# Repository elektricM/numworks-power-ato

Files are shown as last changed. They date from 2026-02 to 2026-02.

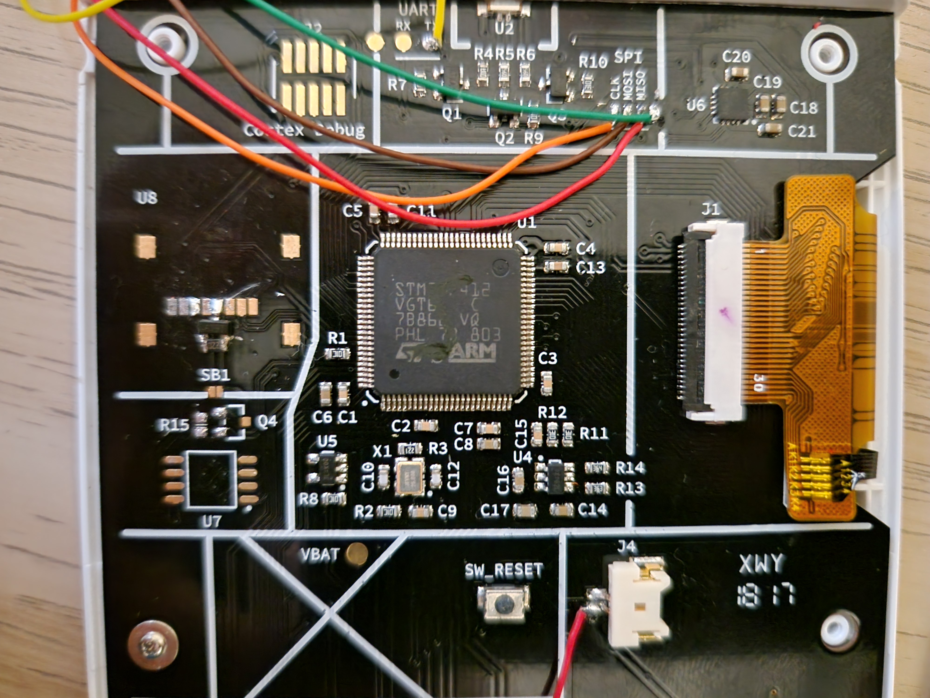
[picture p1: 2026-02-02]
docs/photos/n0100-pcb-closeup.jpg

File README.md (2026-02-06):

# NumWorks N0100 Power Module



[]()

Custom power management board for running a Raspberry Pi Zero 2W inside a NumWorks N0100 calculator.

Schematic

## Why This Exists

The [numworks-rpi](https://github.com/elektricM/numworks-rpi) project replaces the internals of a NumWorks calculator with a Raspberry Pi Zero 2W running Linux. This requires a custom power solution that can:
- ✅ Charge the Li-Ion battery (replacing the failed RT9526A charger)
- ✅ Protect the battery (overcurrent, overvoltage, undervoltage)
- ✅ Provide stable 5V power for the Raspberry Pi from a 3.7V battery
- ✅ Fit within the calculator's tight space constraints (38x24mm max)

This board does all of that in a single custom PCB.

## What It Does

**Three integrated circuits on one compact board:**

### 1. TP4056 Li-Ion Charger
Replaces the dead RT9526A charger on the original calculator. Standard 1A charge current with automatic termination.

### 2. DW01A + FS8205A Battery Protection
Complete protection circuitry:
- Overcurrent protection (discharge > 3A, charge > 1.5A)
- Overvoltage protection (> 4.25V)
- Undervoltage protection (< 2.4V)
- Auto-recovery when fault conditions clear

### 3. TPS63020 Buck-Boost Converter
Maintains stable 5V output for the Raspberry Pi across the full battery voltage range (3.0V - 4.2V):
- 95% efficiency typical
- Up to 2A output current
- Seamless transition between buck and boost modes

## Why atopile?

This board is designed with [atopile](https://atopile.io), a modern code-first PCB design tool, instead of traditional KiCad or Altium.

**Benefits:**
- 📝 **Version control friendly** — Circuit described in plain text, easy to diff and review
- 🔍 **Automatic part sourcing** — Searches JLCPCB/LCSC inventory for available parts
- 🔄 **Parametric components** — Easy to swap parts while maintaining electrical compatibility
- 🧪 **Design validation** — Catch errors before layout with built-in checking

All components are sourced from JLCPCB/LCSC for straightforward assembly and low-cost manufacturing.

## Component Selection

| Component | Part Number | Why This One |
|---|---|---|
| Charger IC | TP4056 | Ubiquitous, cheap (~$0.10), proven reliability, 1A charge current matches original |
| Protection IC | DW01A | Industry standard battery protection IC, tiny SOT-23-6 package |
| Protection MOSFETs | FS8205A | Dual N-channel MOSFETs in SOT-23-6, perfectly matched for DW01A |
| Buck-Boost | TPS63020 | Can operate in buck OR boost mode, 95% efficiency, up to 2A output, small footprint |

Full design rationale and power budget analysis available in [docs/design-spec.md](docs/design-spec.md).

## Board Specifications

- **Dimensions:** 38mm × 24mm (fits NumWorks internal space)
- **Input voltage:** USB 5V (charging) or battery 3.0V-4.2V (operation)
- **Output voltage:** 5.0V ± 2% (for Raspberry Pi)
- **Maximum output current:** 2A continuous (sufficient for RPi Zero 2W)
- **Charge current:** 1A (programmable via resistor)
- **Layers:** 2-layer PCB
- **Manufacturing:** Designed for JLCPCB assembly

## Status

✅ **Tested and working** — Successfully integrated into the numworks-rpi project. Powers the Raspberry Pi Zero 2W reliably with good battery life.

## Building

Requires [atopile](https://atopile.io) v0.14.0 or newer.

```bash
# Install atopile
pip install atopile

# Build the design
ato build

# Output files will be in build/
```

The build generates:
- Netlist (JSON)
- Schematic (SVG)
- Layout files for manufacturing

## Related Projects

- **[numworks-rpi](https://github.com/elektricM/numworks-rpi)** — Main project: Raspberry Pi Zero 2W running Linux inside a NumWorks calculator
- **[numworks-power-pcb](https://github.com/elektricM/numworks-power-pcb)** — Earlier KiCad-based version of this board (deprecated)

## Documentation

- **[Design Spec](docs/design-spec.md)** — Complete circuit design, pin mappings, component selection rationale, and power budget calculations
- **[Tool Learnings](docs/tool-learnings.md)** — Comparison of PCB design tools: atopile vs traditional EDA

## Project Structure

```
numworks-power-ato/
├── ato.yaml              # atopile project configuration
├── main.ato              # Top-level circuit definition
├── parts/                # Component library (charger, protection, buck-boost)
├── layouts/              # PCB layout definitions
├── docs/                 # Design documentation
│   ├── design-spec.md    # Circuit design and analysis
│   └── tool-learnings.md # PCB tool comparison
├── schematic.svg         # Generated schematic image
└── *.py                  # Build and layout automation scripts
```

## Manufacturing

This board is designed for JLCPCB's PCB assembly service:
1. Export Gerber files from atopile build output
2. Upload to JLCPCB
3. All components are in JLCPCB's parts library
4. SMT assembly is straightforward with BOM and pick-place files

## License

MIT License — see [LICENSE.txt](LICENSE.txt) for details.

---

**Part of the [numworks-rpi](https://github.com/elektricM/numworks-rpi) project**

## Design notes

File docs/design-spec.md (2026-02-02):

# NumWorks N0100 Power Module — Design Spec

## Purpose
Internal daughter board replacing the broken RT9526A charger on a NumWorks N0100 calculator.
Also adds 5V regulated output for a Raspberry Pi Zero 2W mounted inside the calculator.

## Target Hardware
- **Calculator:** NumWorks N0100 (STM32F412, micro-USB, 1820mAh Li-Ion battery, 2.8V logic rail)
- **Schematics:** https://tiplanet.org/forum/archives_voir.php?id=2637409

## What This Board Does
1. **Li-Ion charging** — TP4056 linear charger, 500mA from USB
2. **Battery protection** — DW01A + FS8205A (over-charge, over-discharge, over-current, short-circuit)
3. **5V buck-boost** — TPS63020, 3.0–4.2V → 5.0V for Pi Zero 2W (up to 2A transient)
4. **Battery monitoring** — 1:1 voltage divider for STM32 ADC

## What This Board Does NOT Include
- ❌ USB connector (on mainboard)
- ❌ JST battery connector (wires/solder pads)
- ❌ ESD protection (USBLC6-2SC6 already on mainboard)
- ❌ 2.8V LDO (RT9078 stays on mainboard)
- ❌ Backlight driver (RT9365 stays on mainboard)

## Physical Constraints
- Board sits inside the calculator — must be small and flat
- No tall components, no through-hole connectors
- All connections via solder pads + wires to mainboard
- Passives: 0402/0603 preferred

## Wire Signals to Mainboard
| Signal | Direction | Connects To | Notes |
|---|---|---|---|
| VUSB | In from MB | Mainboard USB 5V | Power source for charger |
| GND | Common | System ground | |
| VBAT_RAW  | Bidirectional | Battery + | Charger output / battery input |
| BAT_NEG | To battery | Battery − | Through protection MOSFETs |
| V5_PI | Out to Pi | Pi Zero 5V rail | TPS63020 output |
| PI_EN | In from STM32 | STM32 PB9 | High = enable Pi power |
| CHG_STAT  | Out to STM32  | STM32 PA0 | Active-low charging indicator |
| VBAT_SNS  | Out to STM32  | STM32 PA1 | Battery voltage / 2 (ADC input) |

## ICs
| IC | Function | Package | LCSC |
|---|---|---|---|
| TP4056 | Li-Ion charger | ESOP-8 | C16581 |
| DW01A | Battery protection | SOT-23-6  | C351410  |
| FS8205A | Dual N-MOSFET | SOT-23-6  | C32254 |
| TPS63020 | Buck-boost converter | VSON-14 | C15483 |

## Key Design Values
- **Charge current:** 500mA (R_PROG = 2kΩ)
- **Buck-boost output:** 5.045V (R_top = 1MΩ, R_bot = 110kΩ)
- **PI_EN default:** OFF (100kΩ pull-down, STM32 drives high)
- **PS/SYNC:** Forced PWM mode (100kΩ pull-down)
- **Battery monitor:** 1:1 divider (2× 1MΩ) + 100nF filter → VBAT/2 at ADC
- **Inductor:** 2.2µH, 3A rated
- **Current sense:** 100Ω between battery − and DW01A VM pin

## Power Budget (1820mAh battery)
- Calculator only: ~90mA → ~20h runtime
- Pi idle: ~250mA → ~5h runtime (from ~1450mAh usable)
- Pi + calc active: ~350mA → ~4h runtime

## Existing Mainboard Components (kept)
- **RT9078:** 2.8V LDO for STM32 logic
- **RT9365:** Backlight LED driver
- **USBLC6-2SC6:** USB ESD protection

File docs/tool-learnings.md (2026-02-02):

# PCB Design Tools — Learnings & Comparison

## Project Context
- **Goal:** Internal daughter board for NumWorks N0100 calculator
- **Function:** TP4056 charger + DW01A/FS8205A protection + TPS63020 5V boost for Raspberry Pi Zero 2W
- **Key constraint:** This is an INTERNAL board — no USB connector, no battery connector (JST), no ESD. VUSB comes via wire from mainboard. Battery connects directly via solder pads/wires. Minimal connectors.
- **Board sits inside the calculator** — space is extremely limited

## What NOT to Include
- ❌ USB connector (already on mainboard)
- ❌ JST battery connector (battery soldered/wired directly)
- ❌ ESD protection (already on mainboard)
- ❌ Excessive through-hole pin headers — use solder pads or minimal flat connectors
- The board should be as small and flat as possible

## Tool 1: Zener (Diode `pcb` CLI)

### What It Is
- Rust CLI tool from [Diode Inc](https://github.com/diodeinc/pcb)
- HDL language (`.zen` files) based on Starlark (Python-like)
- Version: 0.3.31
- ~Newer, smaller community

### What Works
- `pcb build` — compiles .zen to netlist, validates, generates BOM
- `pcb layout` — places all footprints with net assignments into a `.kicad_pcb`
- `pcb bom` — auto-matches generic passives to real MPNs (Murata caps, Panasonic resistors)
- `pcb search` — component search
- References KiCad symbol/footprint libraries directly (`@kicad-symbols/`, `@kicad-footprints/`)
- **VSCode extension** (`diode-inc.zener`) renders .zen as interactive schematics — **this is the visualization solution**

### What Doesn't Work Well
- Layout is grid-placed only (no intelligent grouping or autorouting)
- No CLI schematic export (must use VSCode extension for visual schematics)
- Custom components with `Symbol(definition=...)` work for build but don't get real KiCad symbols in schematic view
- Auth required for some features — login via `pcb auth login` (browser OAuth flow)

### Auth Status
- Martin has an account on the Mac (email: dolezelektricm@gmail.com)
- Token refreshes with `pcb auth refresh`
- **Server needs its own login** — can be done via browser, needs email OTP

### Key Syntax
```python
# Generics (auto-matched to real parts)
Resistor = Module("@stdlib/generics/Resistor.zen")
Capacitor = Module("@stdlib/generics/Capacitor.zen")

# KiCad library components
Component(
    name = "U1",
    symbol = Symbol(library = "@kicad-symbols/Battery_Management.kicad_sym", name = "DW01A"),
    footprint = File("@kicad-footprints/Package_TO_SOT_SMD.pretty/SOT-23-6.kicad_mod"),
    mpn = "DW01A",
    pins = { "VCC": vcc_net, "GND": gnd_net, ... },
)

# Nets
gnd = Ground("GND")
vcc = Power("VCC", voltage = VoltageRange("3.0V to 4.2V"))
my_net = Net("MY_NET")
```

### Project Location
- Workspace: `~/clawd/numworks-power-pcb/`
- GitHub: `elektricM/numworks-power-pcb`
- Entry: `boards/PowerModule/PowerModule.zen`

---

## Tool 2: atopile

### What It Is
- Python-based PCB design language (`.ato` files)
- From [atopile](https://github.com/atopile/atopile) — ~3k GitHub stars
- Version: 0.12.5 (latest: 0.14.0)
- More active community, Discord, package registry

### What Works
- `ato create part` — fetches component from JLCPCB/LCSC by part number, auto-generates footprint + symbol + 3D model
- `ato build` — compiles, picks passive components automatically from JLCPCB library
- `ato view` — schematic/block diagram visualization
- **VSCode/Cursor extension** available
- Package registry at packages.atopile.io
- Has MCP server for AI coding assistance

### What Doesn't Work Well (v0.12.5)
- `Resistor`, `Capacitor`, `Inductor` are NOT importable from `"generics/*.ato"` — the import path is wrong or they're Python-native classes in faebryk
- The `#pragma experiment("TRAITS")` flag is needed for component traits
- Interactive CLI (`ato create part`) doesn't work well in non-interactive/piped mode
- KiCad plugin installation fails on headless server (needs KiCad config path)

### Auth
- No auth needed for basic usage
- JLCPCB component fetch works without login

### Key Syntax
```
#pragma experiment("TRAITS")

module MyCircuit:
    signal vcc
    signal gnd

    r1 = new Resistor
    r1.resistance = 10kohm +/- 5%
    r1.package = "0603"
    r1.p1 ~ vcc
    r1.p2 ~ gnd

    ic = new MyCustomComponent
    ic.VIN ~ vcc
    ic.GND ~ gnd
```

### Component Creation
```bash
# Search by LCSC part number
ato create part  # then enter C16581 for TP4056

# Successfully fetched:
# - C16581 → TP4056 (TOPPOWER)
# - C351410 → DW01A (PUOLOP)
# - C32254 → FS8205A (Fortune Semicon)
# - C15483 → TPS63020DSJR (Texas Instruments)
```

### Project Location
- Workspace: `~/clawd/numworks-power-ato/`
- Not yet on GitHub

---

## Comparison

| Feature | Zener | atopile |
|---|---|---|
| Language | Starlark (.zen) | Custom (.ato) |
| Community | Smaller | ~3k stars, active |
| Passive auto-pick | ✅ Via stdlib generics | ✅ Via JLCPCB database |
| Component fetch | Manual symbol/footprint | `ato create part` (auto) |
| Schematic view | VSCode extension | `ato view` + VSCode |
| KiCad output | ✅ .kicad_pcb | ✅ .kicad_pcb |
| BOM | ✅ Great | ✅ Auto from JLCPCB |
| Layout | Grid placement | Grid placement |
| Maturity | Newer | More mature |
| Docs | Embedded (`pcb doc`) | docs.atopile.io |

## Recommendation
Both tools produce KiCad PCB output with grid-placed footprints. Manual routing in KiCad is needed either way.

**atopile** has the edge for:
- Larger community, more examples
- Better component fetching (LCSC/JLCPCB integrated)
- `ato view` for visualization without needing VSCode
- Auto parametric picking of discretes

**Zener** has the edge for:
- Direct KiCad library integration
- BOM with real MPN matching
- Slightly cleaner syntax
- Built-in simulation (`pcb sim`)

## Next Steps
1. Pick one tool (recommend trying atopile v0.14.0 for better stability)
2. Design the circuit with MINIMAL connectors — just solder pads for wires
3. Get schematic visualization working first
4. Then proceed to layout

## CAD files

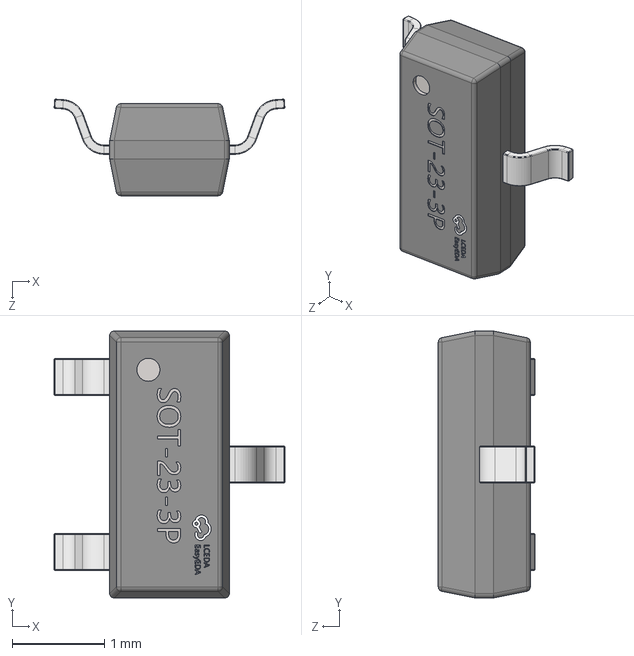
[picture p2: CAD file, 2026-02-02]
parts/Alpha___Omega_Semicon_AO3401A/SOT-23-3P_L2.9-W1.3-H1.0-LS2.4-P0.95.step
2.51 x 2.90 x 1.05 mm

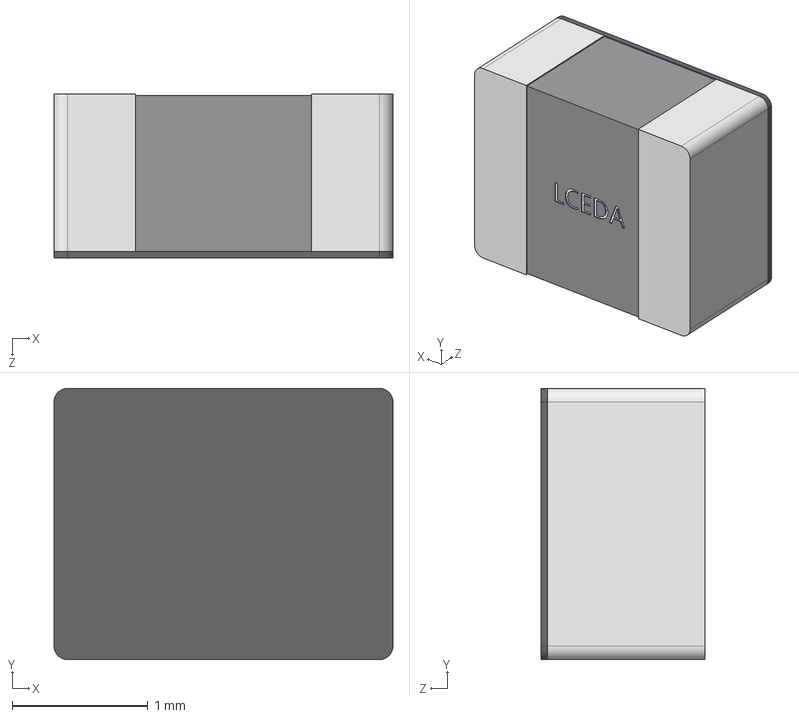
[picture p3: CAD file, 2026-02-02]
parts/cjiang_FTC252012S2R2MBCA/IND-SMD_L2.5-W2.0_MHCHL2520.STEP
2.50 x 2.00 x 1.21 mm

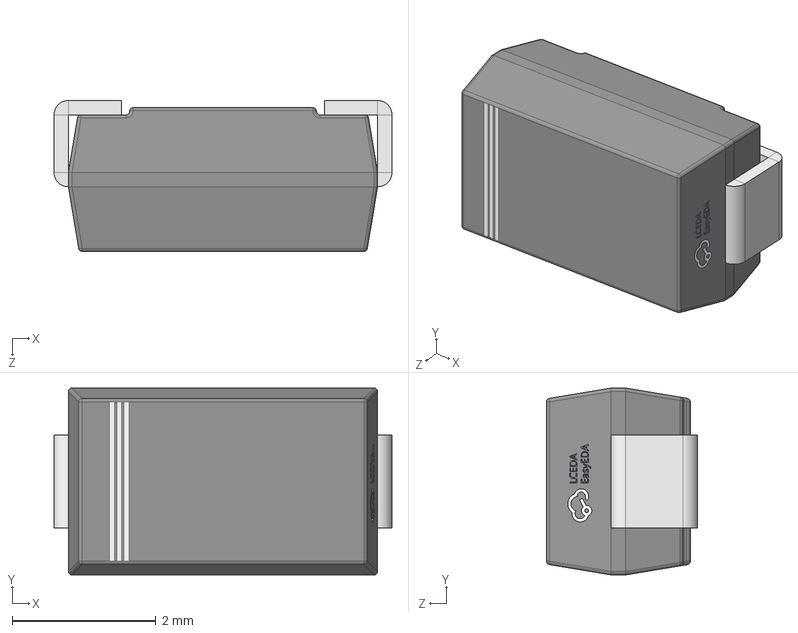
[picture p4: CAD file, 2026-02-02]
parts/MDD_Microdiode_Electronics_SS34/SMA_L4.3-W2.6-LS5.2-RD.step
4.70 x 2.60 x 2.10 mm

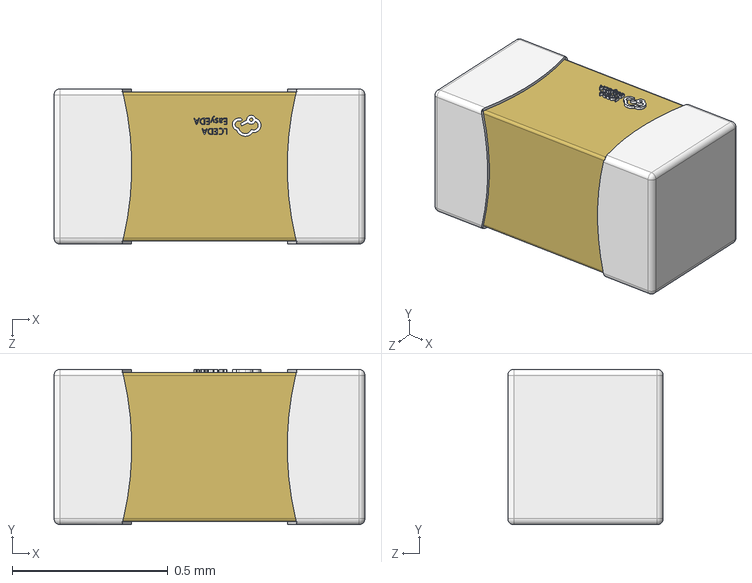
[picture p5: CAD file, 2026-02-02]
parts/Samsung_Electro_Mechanics_CL05B104KO5NNNC/C0402_L1.0-W0.5-H0.5.step
1.00 x 0.5 x 0.5 mm

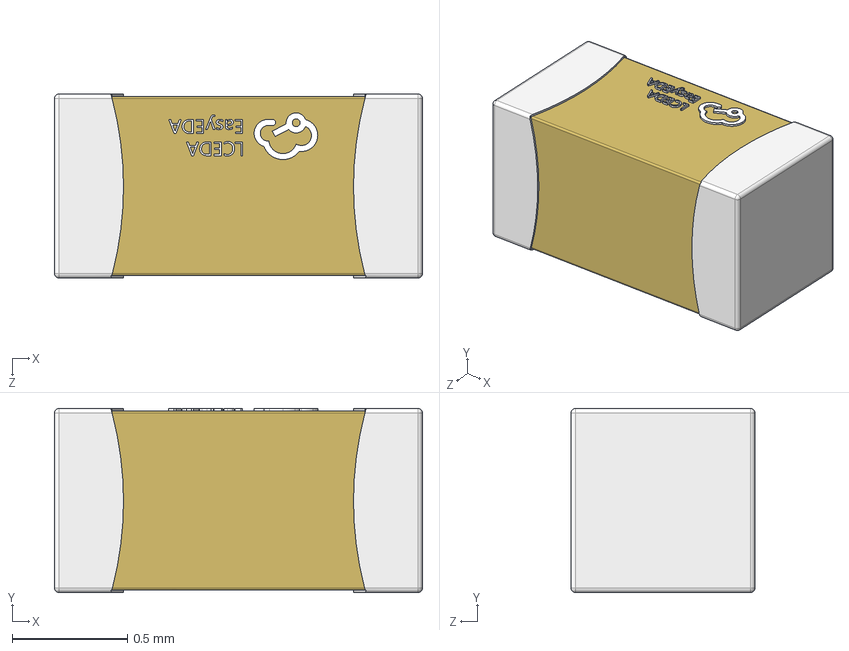
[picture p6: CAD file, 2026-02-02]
parts/Samsung_Electro_Mechanics_CL10A106KP8NNNC/C0603_L1.6-W0.8-H0.8.step
1.60 x 0.8 x 0.8 mm

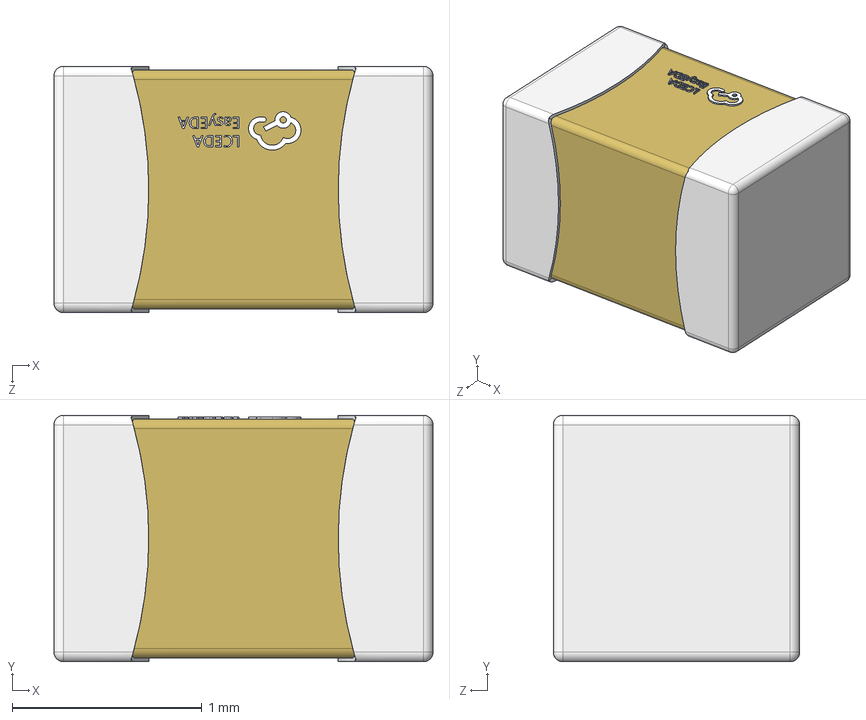
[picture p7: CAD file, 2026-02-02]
parts/Samsung_Electro_Mechanics_CL21A226MAQNNNE/C0805_L2.0-W1.3-H1.3.step
2.00 x 1.30 x 1.30 mm

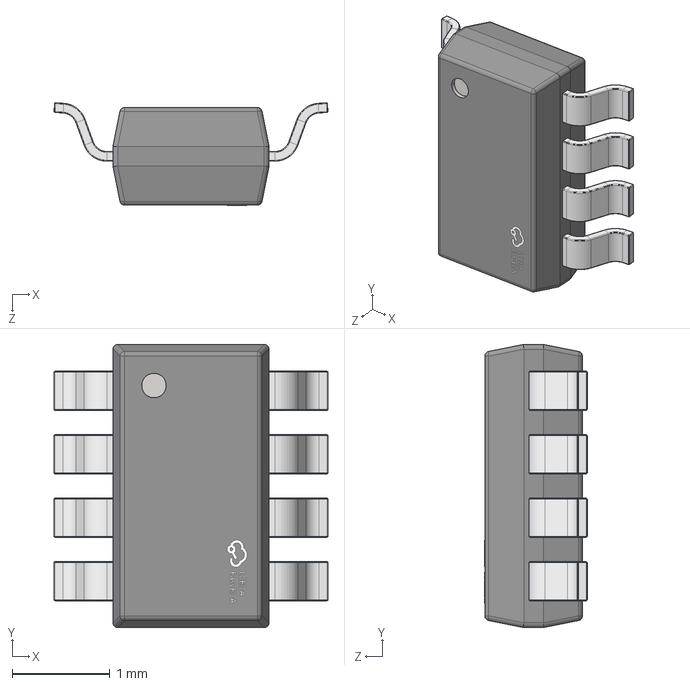
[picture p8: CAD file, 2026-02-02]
parts/Silergy_Corp_SY8303AIC/TSOT-23-8_L2.9-W1.6-H1.1-LS2.8-P0.65.step
2.81 x 2.90 x 1.05 mm

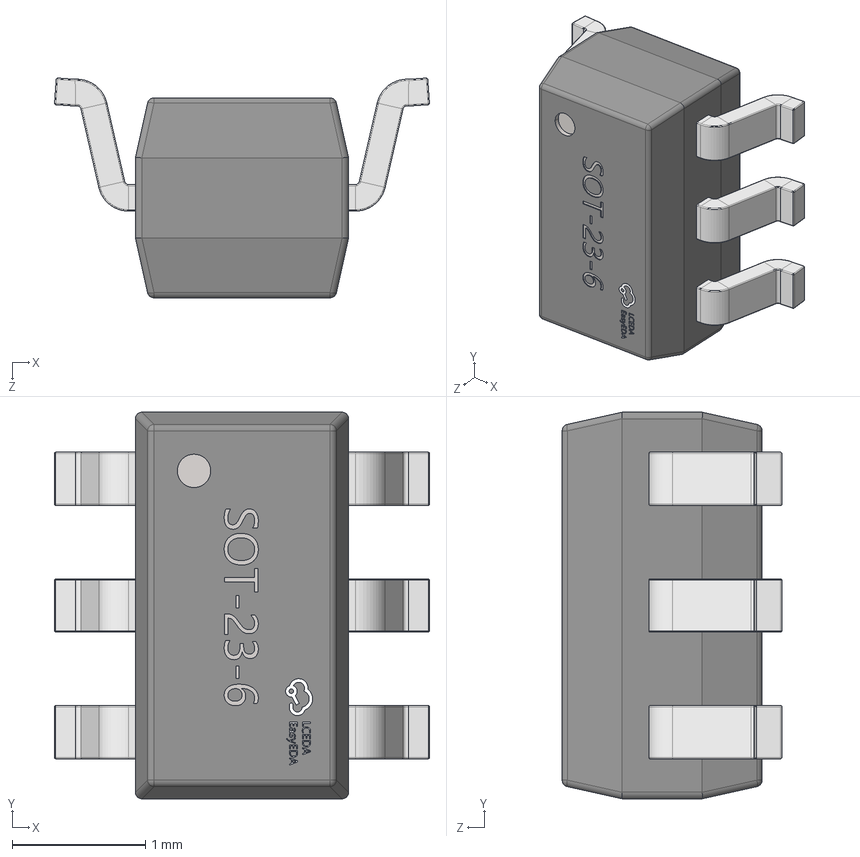
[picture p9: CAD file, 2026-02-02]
parts/SX_SX1308/SOT-23-6_L2.9-W1.6-H1.5-LS2.8-P0.95.step
2.81 x 2.90 x 1.65 mm

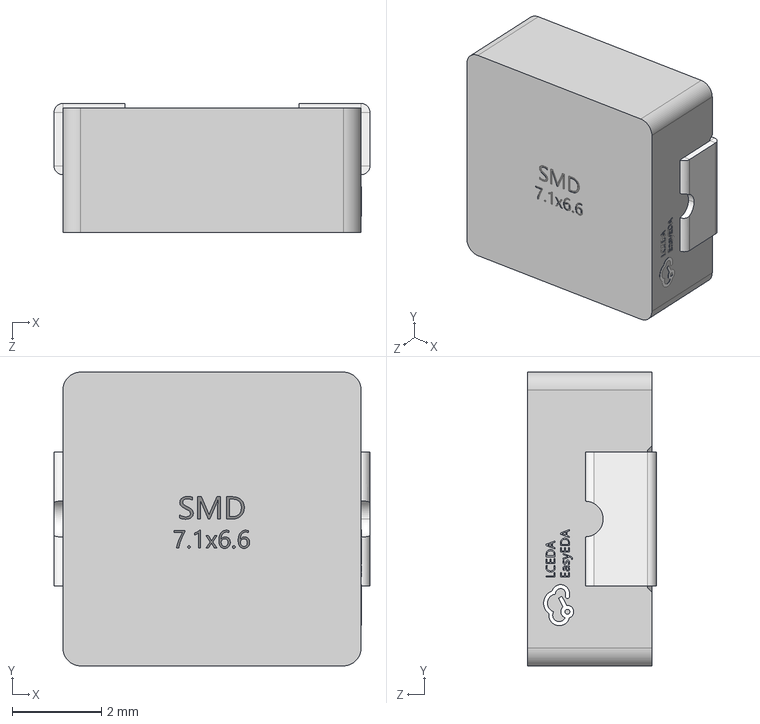
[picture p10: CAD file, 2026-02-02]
parts/SXN_SMMS0630_220M/IND-SMD_L7.1-W6.6-H2.8.step
7.10 x 6.60 x 2.90 mm

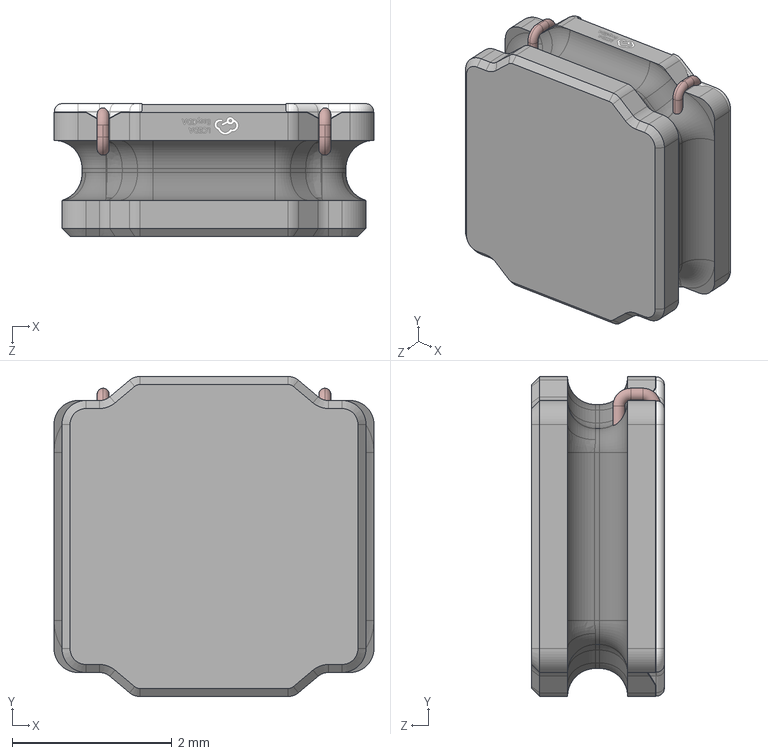
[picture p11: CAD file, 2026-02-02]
parts/SXN_SMNR4020_22UH/IND-SMD_L4.0-W4.0-H1.65.STEP
4.00 x 4.00 x 1.66 mm

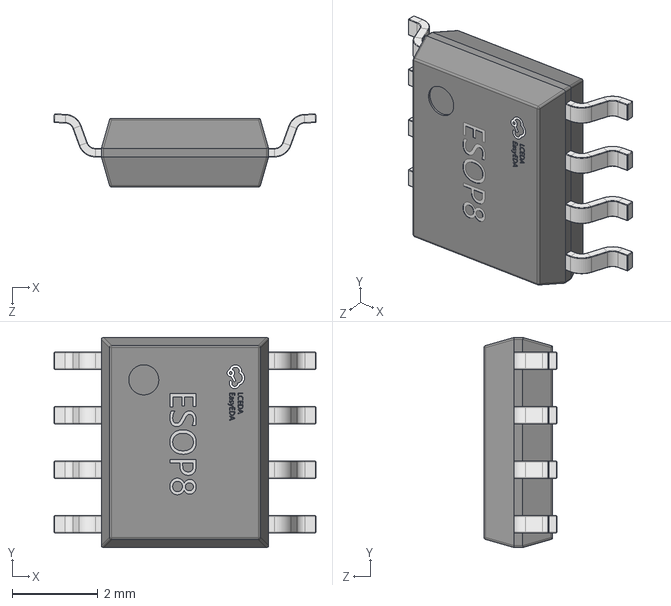
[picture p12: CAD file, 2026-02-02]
parts/TOPPOWER_TP4056_42_ESOP8/ESOP-8_L4.9-W3.9-H1.6-LS6.0-P1.27.step
6.11 x 4.90 x 1.70 mm

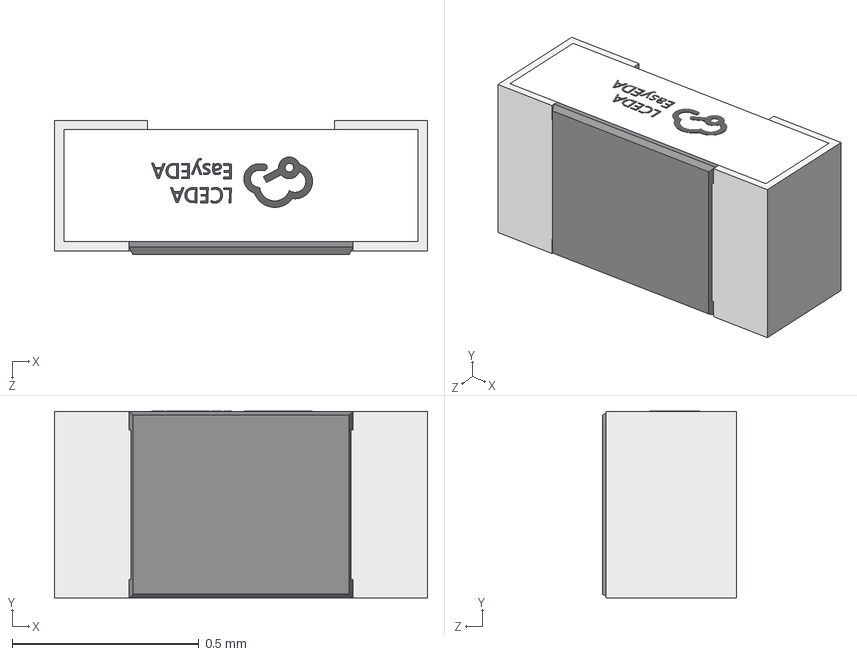
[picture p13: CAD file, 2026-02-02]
parts/UNI_ROYAL_0402WGF2203TCE/R0402_L1.0-W0.5-H0.4.step
1.00 x 0.501 x 0.36 mm

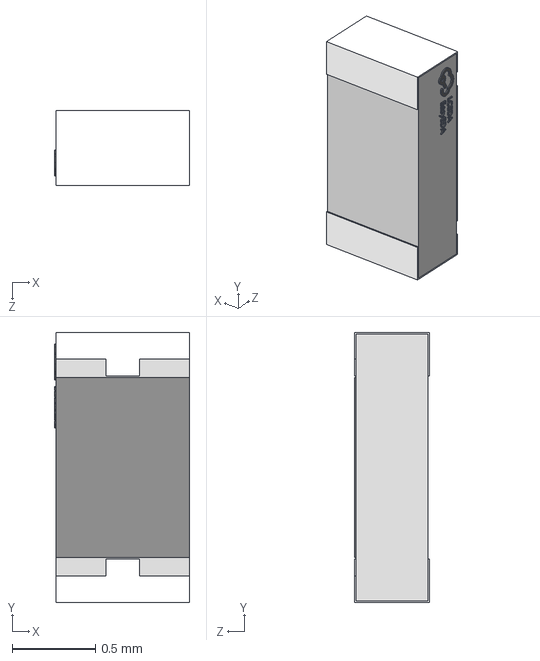
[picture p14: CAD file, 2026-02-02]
parts/UNI_ROYAL_0603WAF2203T5E/R0603.STEP
0.81 x 1.62 x 0.45 mm

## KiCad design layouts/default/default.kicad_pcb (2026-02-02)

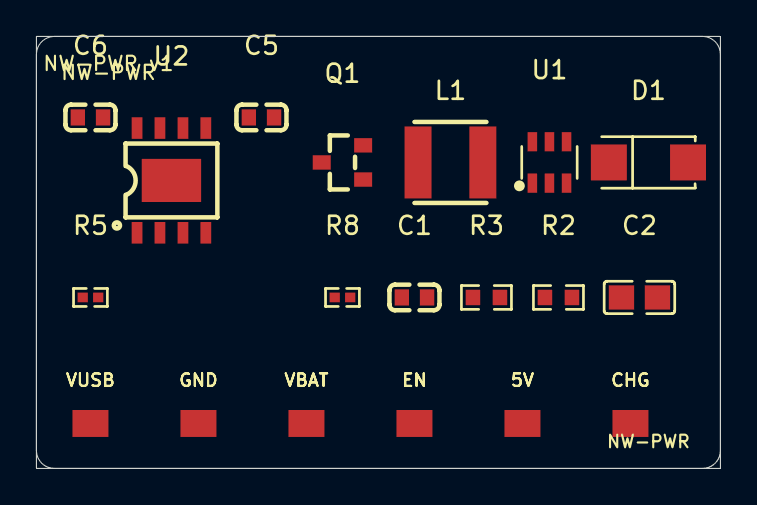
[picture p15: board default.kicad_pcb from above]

Board: 2 copper layers, 38.0 x 24.0 mm, 19 parts (0 on the bottom side), 10 nets, no tracks yet.

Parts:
C1, C5, C6: 0F; C0603
C2: 0F; C0805
D1: SMA_L4.3-W2.6-LS5.2-RD
J1, J2, J3, J4, J5, J6: SolderPad
L1: IND-SMD_L4.0-W4.0_LQH44PN2R2MP0L
Q1: SOT-23_L2.9-W1.3-P1.90-LS2.4-BR
R2: 30000Ω; R0603
R3: 220000Ω; R0603
R5: 2000Ω; R0402
R8: 100000Ω; R0402
U1: SOT-23-6_L2.9-W1.6-P0.95-LS2.8-BL
U2: ESOP-8_L4.9-W3.9-P1.27-LS6.0-BL-EP

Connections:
2: D1.2, L1.2, U1.1
FB: R2.1, R3.2, U1.3
PROG: R5.1, U2.2
c_bat-power-hv: C5.1, J5.1, Q1.2, R8.1, U2.5
c_in-power-hv: C6.1, J6.1, U2.4, U2.8
c_out-power-hv: C2.1, D1.1, J4.1, R3.1
chg_stat: J1.1, U2.7
hv: C1.1, L1.1, Q1.3, U1.4, U1.5
lv: C1.2, C2.2, C5.2, C6.2, J2.1, R2.2, R5.2, U1.2, U2.1, U2.3, U2.9
pi_en: J3.1, Q1.1, R8.2

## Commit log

2026-02-02 NumWorks N0100 power module - atopile build (TP4056 + DW01A + TPS63020)
    [C0402_L1.0-W0.5-H0.5.step, C0603_L1.6-W0.8-H0.8.step, C0805_L2.0-W1.3-H1.3.step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]
2026-02-02 Upgrade to atopile v0.14.0 (Python 3.14), fix pin names
    [default.kicad_pcb]
2026-02-02 Rearrange PCB layout: group by functional block (buck-boost/charger/protection/monitor), add 39.5x16.5mm board outline
    [default.kicad_pcb]
2026-02-02 Clean slate: remove old PCB code, keep docs (design spec + tool learnings)
    [C0402_L1.0-W0.5-H0.5.step, C0603_L1.6-W0.8-H0.8.step, C0805_L2.0-W1.3-H1.3.step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]
2026-02-02 Fresh build: TP4056 charger + DW01A/FS8205A protection + TPS63020 buck-boost, layout grouped by block (39x17mm)
    [C0402_L1.0-W0.5-H0.5.step, C0603_L1.6-W0.8-H0.8.step, C0805_L2.0-W1.3-H1.3.step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]
2026-02-02 Simplify: remove battery protection, add AO3401A P-MOSFET power switch for Pi (35x15mm, 19 components)
    [R0402_L1.0-W0.5-H0.4.step, SOT-23-3P_L2.9-W1.3-H1.0-LS2.4-P0.95.step, SOT-23-6_L2.9-W1.6-H1.5-LS2.8-P0.95.step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]
2026-02-02 Remove battery monitor (mainboard handles it), 16 components on 32x15mm
    Firmware confirmed: zardam's rpi.h uses PB9 P-channel MOSFET
    - PowerPin(GPIOB, 9), drive low = on, float = off
    - Matches our AO3401A + 100k pull-up circuit exactly
    [default.kicad_pcb]
2026-02-02 Replace TPS63020 with SX1308 boost converter
    - SX1308 (C78162): SOT-23-6, 2A output, hand-solderable
    - Added SS34 Schottky diode (C8678) for async boost rectification
    - Simplified MOSFET gate: removed unnecessary R_gate to GND, keep only 100kΩ pull-up
    - Removed TPS63020 (VSON-14 pads too small for hand soldering)
    - Feedback divider: 220kΩ/30kΩ → 5.0V output
    - BOM reduced from 16 to 12 components
    [IND-SMD_L7.1-W6.6-H2.8.step, R0402_L1.0-W0.5-H0.4.step, SMA_L4.3-W2.6-LS5.2-RD.step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]
2026-02-02 Optimize JLCPCB cost: use 0603 feedback resistors (Basic parts)
    30kΩ and 220kΩ are Extended in 0402 but Basic in 0603.
    Saves $6 in extended part fees (from $15 to $9).
    [R0603.STEP, default.kicad_pcb]
2026-02-02 Use compact 4x4x2mm inductor (SMNR4020-22UH)
    Replaced bulky 7.3x6.6x3mm inductor with 4x4x2mm shielded version.
    Same 22µH value, 1.05A rated - sufficient for Pi Zero 2W load.
    Max component height now 2.1mm (SS34 Schottky diode).
    [IND-SMD_L4.0-W4.0-H1.65.STEP, default.kicad_pcb]
2026-02-02 Add PCB layout: 6 solder pads, component placement, routing, ground pour
    - Created SolderPad component (2x1.5mm SMD pads) for 6 wire connections
    - Board outline: 30x18mm with rounded corners
    - 3-zone layout: charger (left) → MOSFET (center) → boost (right)
    - Solder pads along bottom edge: VUSB, GND, VBAT, PI_EN, V5_PI, CHG
    - 50 trace segments, 11 vias, GND pour on B.Cu
    - Power traces 0.5mm, signal traces 0.25mm
    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
    [default.kicad_pcb]
2026-02-02 Fix layout: proper pad spacing, clean placement, remove bad routing
    - 6 solder pads evenly spaced along bottom edge (4.8mm apart)
    - Components grouped: charger left, MOSFET center, boost right
    - Removed all programmatic traces/vias/zones - route in KiCad
    - Clean silkscreen labels (VUSB, GND, VBAT, EN, 5V, CHG)
    - 30x18mm board outline
    [default.kicad_pcb]
2026-02-02 Add schematic diagram SVG
2026-02-02 Regenerate schematic from atopile graph data (verified netlist)
2026-02-02 Proper schematic via netlistsvg (Yosys JSON netlist)
2026-02-02 Clean schematic: fix cell names, no duplicates
2026-02-02 Fix all 6 solder pad positions (were stacked, now spaced)
    [default.kicad_pcb]
2026-02-02 Layout v2: proper spacing, 38x24mm board, GND pour, no overlaps
    - Components spaced by actual footprint size
    - 3 zones: charger (left) | MOSFET (center) | boost (right)
    - Row 1 (y=87): ICs, inductor, diode
    - Row 2 (y=95): small passives
    - Row 3 (y=101.5): 6 solder pads, 6mm apart
    - GND copper pour on B.Cu
    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
    [default.kicad_pcb]
2026-02-02 Layout v3: rounded corners, all components horizontal, proper spacing
    - 1mm rounded corners on board outline
    - All passives horizontal (no rotation surprises)
    - C6 and C5 above U2 (not overlapping)
    - R5 moved to row 2 with space
    - R2/R3 feedback divider 4mm apart (no overlap)
    - C1/C2 properly spaced in boost row 2
    [default.kicad_pcb]
2026-02-02 Fix text: move refs to sides, hide values, clean NW-PWR
    [default.kicad_pcb]
